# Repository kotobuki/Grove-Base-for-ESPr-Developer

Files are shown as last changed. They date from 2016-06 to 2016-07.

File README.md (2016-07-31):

# Grove Base for ESPr Developer

A bridge between the [**Grove**](http://www.seeedstudio.com/wiki/Category:Grove) family by the Seeed Studio and [ESPr Developer](https://www.switch-science.com/catalog/2652/) by the Switch Science.

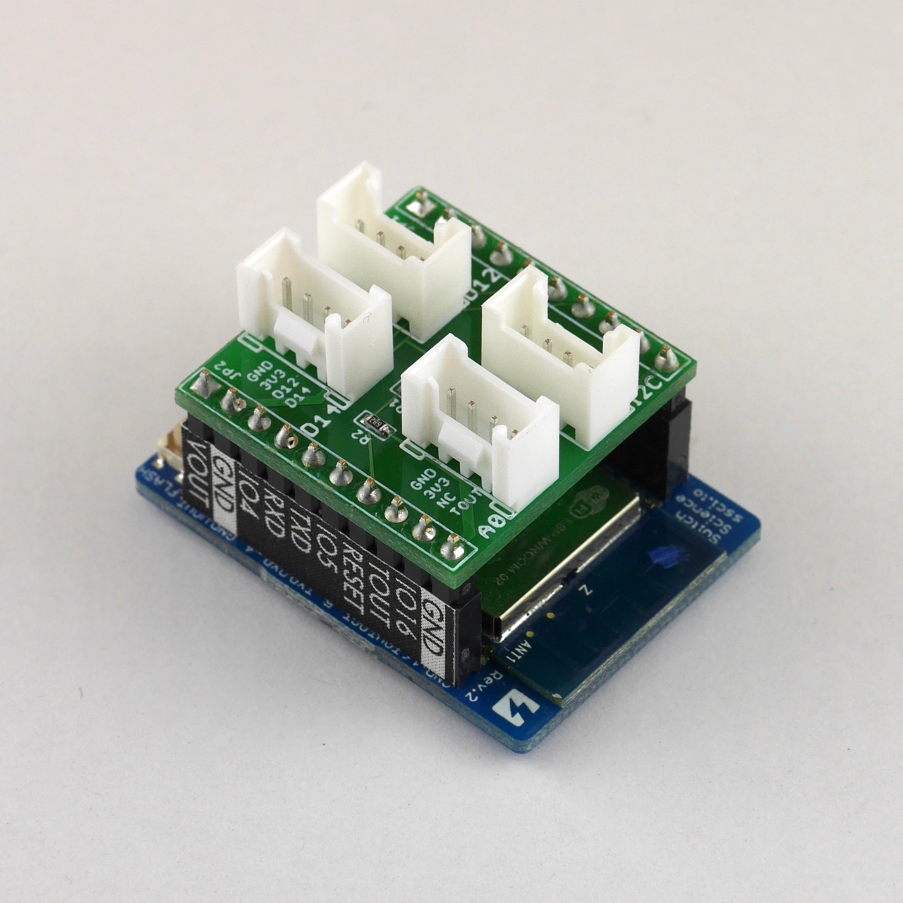
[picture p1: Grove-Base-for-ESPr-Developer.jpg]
Grove Base for ESPr Developer


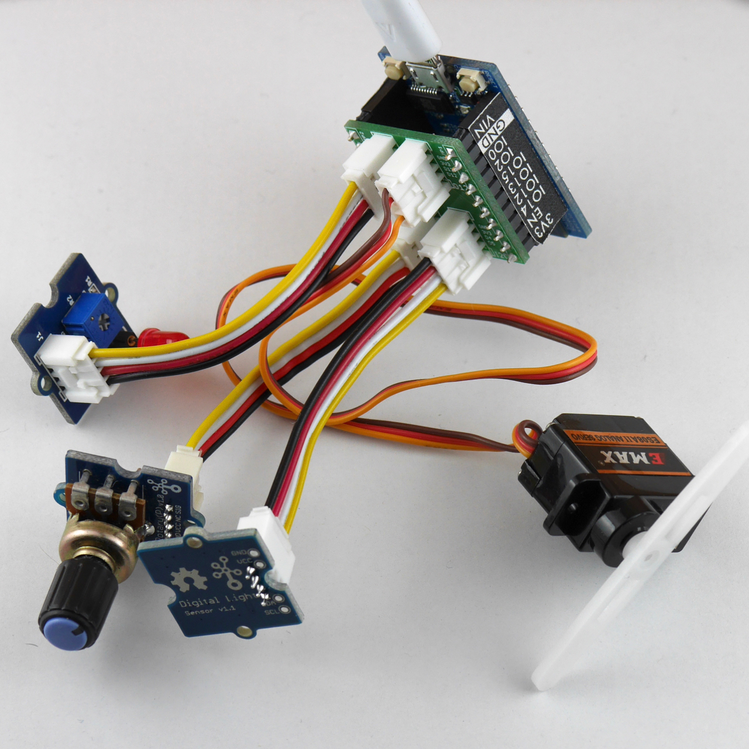
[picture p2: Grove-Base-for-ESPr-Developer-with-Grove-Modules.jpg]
Grove Base for ESPr Developer with Grove Modules


## Bill of Materials

|Part/Designator|Manufacture Part Number/Seeed SKU|Quantity|
|---|---|---|
|PCB||1|
|J1,J2,J3,J4|Seeed SKU: [320110033](http://www.seeedstudio.com/depot/index.php?main_page=opl_info&opl_id=4)|4|
|JP1|Digi-Key: [S9200-ND](http://www.digikey.com/product-search/en?keywords=952-1842-ND)|2|
|R1|Digi-Key: [P220KDBCT-ND](http://www.digikey.com/product-search/en?keywords=P220KDBCT-ND)|1|
|R2|Digi-Key: [P100KDBCT-ND](http://www.digikey.com/product-search/en?keywords=P100KDBCT-ND)|1|

## Compatible Grove Modules

* Sensors
  * [Grove - Button](http://www.seeedstudio.com/wiki/Grove_-_Button)
  * [Grove - Switch(P)](http://www.seeedstudio.com/wiki/Grove_-_Switch(P))
  * [Grove - Rotary Angle Sensor](http://www.seeedstudio.com/wiki/Grove_-_Rotary_Angle_Sensor)
  * [Grove - Slide Potentiometer](http://www.seeedstudio.com/wiki/Grove_-_Slide_Potentiometer)
  * [Grove - Touch Sensor](http://www.seeedstudio.com/wiki/Grove_-_Touch_Sensor)
  * [Grove - Light Sensor](http://www.seeedstudio.com/wiki/Grove_-_Light_Sensor)
  * [Grove - Single Axis Analog Gyro](http://www.seeedstudio.com/wiki/Grove_-_Single_Axis_Analog_Gyro)
  * [Grove - 3-Axis Digital Accelerometer (±16g)](http://www.seeedstudio.com/wiki/Grove_-_3-Axis_Digital_Accelerometer(%C2%B116g))
* Actuators
  * [Grove - LED Socket Kit](http://www.seeedstudio.com/wiki/Grove_-_LED)
  * [Grove - Buzzer](http://www.seeedstudio.com/wiki/Grove_-_Buzzer)
  * [Grove - Vibration Motor](http://www.seeedstudio.com/wiki/Grove_-_Vibration_Motor)
  * [Grove - Servo](http://www.seeedstudio.com/wiki/Grove_-_Servo)

## How to 'compile'?

Place an order at the [Fusion PCBA prototype](http://www.seeedstudio.com/service/index.php?r=pcb) service.

# License Information

This design document is licensed by Shigeru Kobayashi under the terms of the [Creative Commons Attribution-ShareAlike 4.0 International Public License](http://creativecommons.org/licenses/by-sa/4.0/).

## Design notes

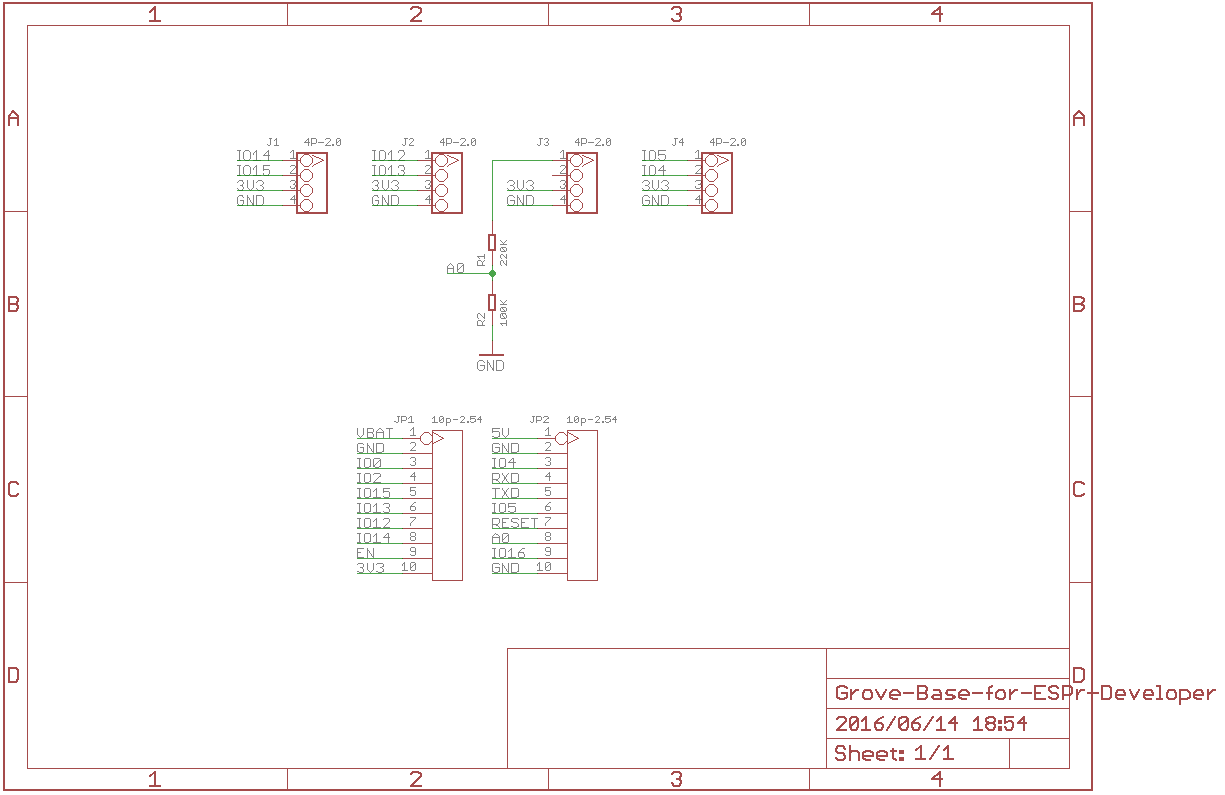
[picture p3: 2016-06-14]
Grove-Base-for-ESPr-Developer_sch.png

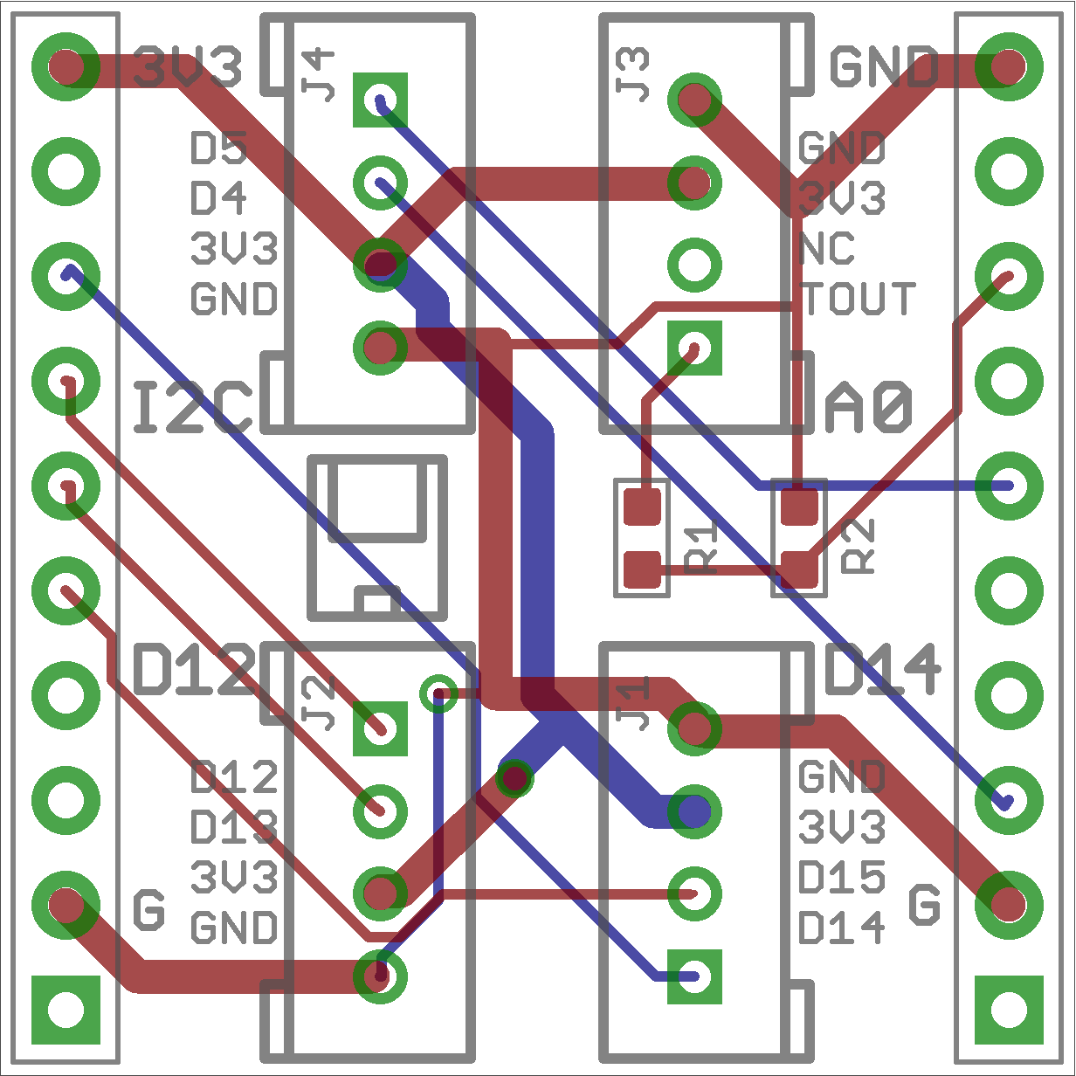
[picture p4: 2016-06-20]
Grove-Base-for-ESPr-Developer_brd.png

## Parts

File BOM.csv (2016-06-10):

Part/Designator | Manufacture Part Number/Seeed SKU | Quantity
J1,J2,J3,J4 | 320110033 | 4
JP1 | M20-9991045 | 2
R1 | ERA-3AEB224V | 1
R2 | ERA-3AEB104V | 1

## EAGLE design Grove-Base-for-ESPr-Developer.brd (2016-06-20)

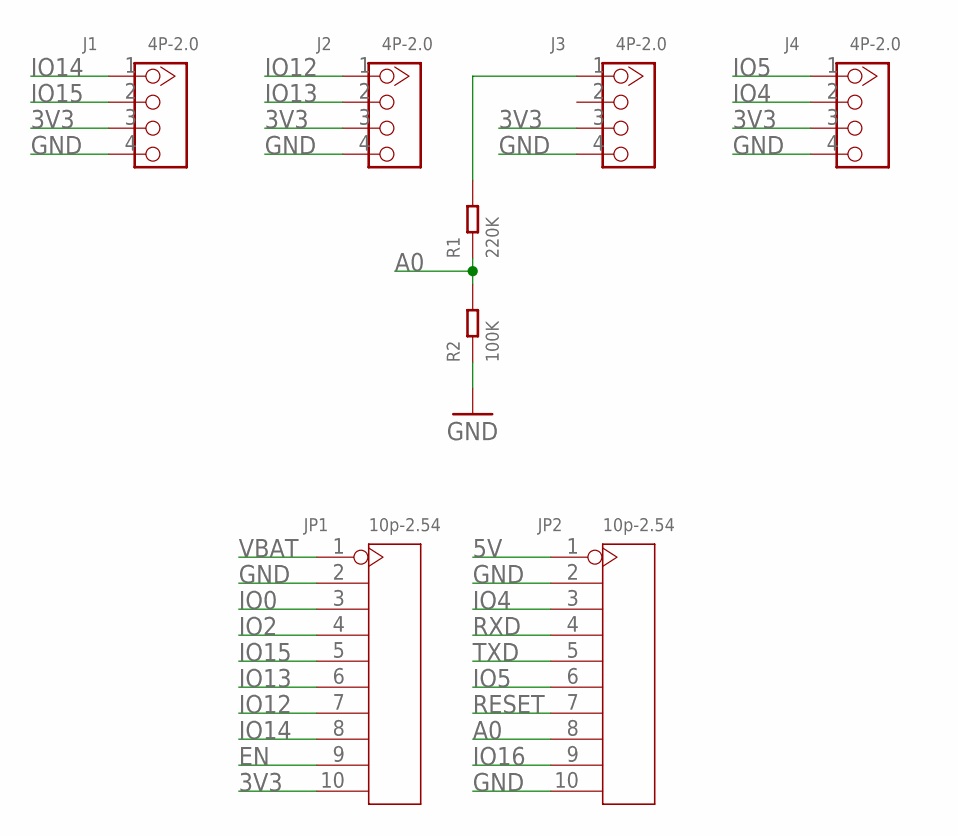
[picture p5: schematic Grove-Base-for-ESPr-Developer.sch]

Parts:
J1, J2, J3, J4: 4P-2.0; HW4-2.0
JP1, JP2: 10p-2.54; H10-2.54
R1: 220K; R0603
R2: 100K; R0603

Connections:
3V3: J1.3, J2.3, J3.3, J4.3, JP1.10
5V: JP2.1
A0: JP2.8, R1.1, R2.2
EN: JP1.9
GND: J1.4, J2.4, J3.4, J4.4, JP1.2, JP2.2, JP2.10, R2.1
IO0: JP1.3
IO2: JP1.4
IO4: J4.2, JP2.3
IO5: J4.1, JP2.6
IO12: J2.1, JP1.7
IO13: J2.2, JP1.6
IO14: J1.1, JP1.8
IO15: J1.2, JP1.5
IO16: JP2.9
unnamed: J3.1, R1.2
RESET: JP2.7
RXD: JP2.4
TXD: JP2.5
VBAT: JP1.1

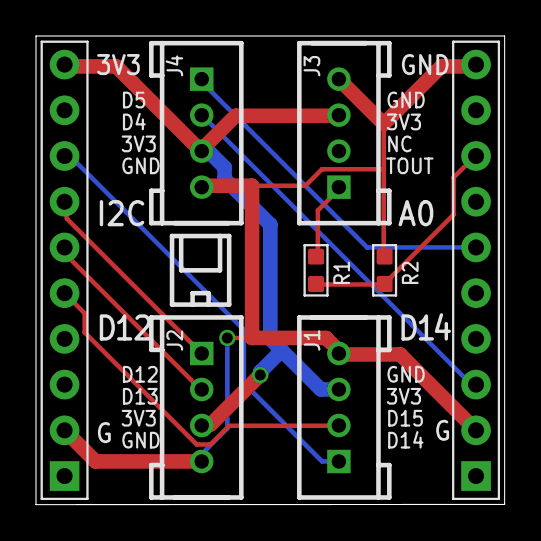
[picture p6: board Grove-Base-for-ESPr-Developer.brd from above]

Board: 2 copper layers, 26.0 x 26.0 mm, 8 parts (0 on the bottom side), 10 nets.

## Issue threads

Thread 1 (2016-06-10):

D14 and A0 pin description silkscreen

Shinichi-Ohki, 2016-06-10:
D14 と A0 のGroveコネクタのピン説明のシルクがそれぞれ
GND
3V3
D12
D14

GND
3V3
NC
TOUT
になっていますが、並び順が逆ではないですか。
D12とI2Cは合っています。

kotobuki, 2016-06-10:
@Shinichi-Ohki
ご指摘ありがとうございました。確かに並び順が間違っておりました。修正いたしました。

afea0fde9c1fa94f5626166e338421810012ed58

Closed 2016-06-10.

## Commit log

2016-06-10 Update silk, BOM and README
    To fix issue #1 and missing components (R1 and R2) in the BOM
    [BOM.csv, Grove-Base-for-ESPr-Developer.brd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]
2016-06-14 Replace the IO14 pin of the IO14 connector with IO15
    [Grove-Base-for-ESPr-Developer.brd, Grove-Base-for-ESPr-Developer.sch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]
2016-06-20 Rotate 180 degree and revise labels
    [Grove-Base-for-ESPr-Developer.brd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]
